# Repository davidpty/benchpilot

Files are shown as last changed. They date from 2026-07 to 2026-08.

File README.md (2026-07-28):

# BenchPilot

**Bench-test your Raymarine autopilot or replace the display on your boat.**

BenchPilot turns an ESP32 touchscreen display (ESP32-2432S028R CYD) into a SeaTalk 1 bus monitor and wireless control head. Connect it to a Raymarine SeaTalk autopilot course computer on the bench or on the water. It generates heading data, decodes autopilot status, and lets you push buttons just like the real ST6002, all through a 320x240 color touchscreen or a WiFi web dashboard on your phone.

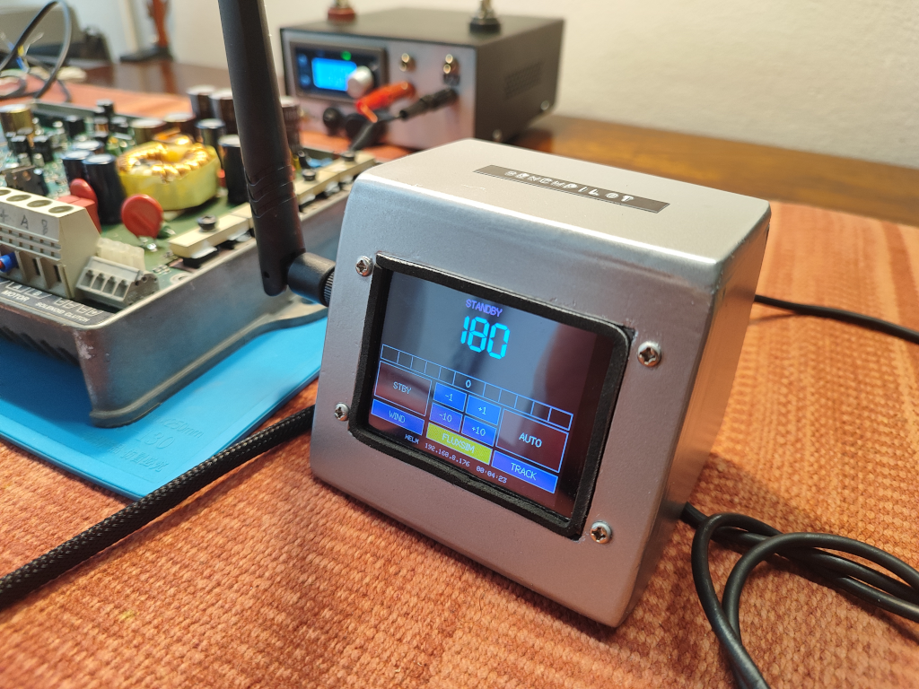
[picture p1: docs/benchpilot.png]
BenchPilot in a PVC foam board housing


## What you can do

- **Replace your display.** Plug it into the existing SeaTalk bus and get heading, rudder, depth, wind, speed, and GPS on the touchscreen with no wiring changes needed.
- **Control from anywhere.** The built-in WiFi web dashboard works on any phone, tablet, or laptop. Adjust course or change modes without reaching for the helm.
- **Monitor.** See all SeaTalk traffic in real time, on-screen or remotely.
- **Simulate.** Built-in heading generator ("FluxSim") sends fake heading datagrams so you can test the autopilot's response on the bench without a compass.
- **Log.** Every bus datagram is saved to the SD card for later analysis.
- **Update.** Flash new firmware over WiFi (OTA) with no cables needed.

You need an ESP32-2432S028R "CYD" display board, a BenchPilot interface
PCB, and a 12V power supply (or the SeaTalk bus itself).

The interface circuit can be built in two ways. The `pcb/` folder contains
a Fritzing file (`BenchPilot_260715.fzz`), schematics, and a DIY etch PDF
(`BenchPilot_260715_diy_etch.pdf`) sized for printing on A4 transfer paper
with a laser printer. Print the PDF, iron the toner onto single-sided
copper clad board, then etch in ferric chloride or ammonium persulfate.
Drill the holes, solder the components, and the board is ready to plug into
the CYD and the SeaTalk bus.

The housing shown in the photo is made from 5mm PVC foam board (Foamex /
Sintra). A craft knife works well for the foam board, it cuts cleanly and
sands smooth. The pieces are glued together with regular PVC glue.

## Getting started

1. Build the interface circuit using the DIY etch PDF or the Fritzing files
2. Copy `src/wifi_config.example.h` to `src/wifi_config.h`, add your WiFi
3. Build and upload with PlatformIO:
   ```
   pio run -t upload
   ```
4. Connect to the BenchPilot WiFi access point or join your network
5. Open http://benchpilot.local in your browser

## License

GNU General Public License v3.0

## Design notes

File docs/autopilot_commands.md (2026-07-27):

# Autopilot Control Reference

## System Architecture

```
ESP32 + BenchPilot Level Shifter (BC557/BC547)
        |
        |  SeaTalk 1 bus (4800 baud, 9-bit, 12V open-collector)
        |
Raymarine ST6002 Display (control head)
        |
Raymarine SmartPilot S3 Course Computer
        |
        |  Motor drive unit
        |
Rudder
```

The ST6002 is the display/control head on the bus. The SmartPilot S3 is the course computer that drives the rudder. The ESP32 (via the discrete transistor level shifter) appears as another device on the bus and can both send commands to and receive status from the autopilot.

## Key Messages for Autopilot

### Transmitted by ESP32 (to control autopilot)

| Message | Command | Function |
|---|---|---|
| 0x86 | Autopilot keystroke | Mode changes, heading changes |
| 0x92 | Set parameter | Response, wind trim, rudder gain |
| 0x87 | Set response level | Deadband control |

### Received by ESP32 (from autopilot)

| Message | Command | Function |
|---|---|---|
| 0x84 | Autopilot status | Heading, mode, rudder, alarms |
| 0x89 | Compass course | Heading from steering compass |
| 0x9C | Heading + rudder | Combined heading and rudder |
| 0x88 | Parameter value | Current parameter settings |
| 0x91 | Rudder gain | Current gain setting |

## Autopilot Commands (0x86)

### Remote Type Encoding

The high nibble of byte 1 encodes the remote type:
- `0x1` = Z101 remote (only sends course changes in Auto mode)
- `0x2` = ST600R remote (full key set — preferred for ESP32)

The AK-Homberger code hard-codes `x = 2` (ST600R remote).

### Command Formats

| Function | Byte 0 | Byte 1 | Byte 2 | Byte 3 | Hex |
|---|---|---|---|---|-----|
| Auto | 0x86 | 0x21 | 0x01 | 0xFE | `86 21 01 FE` |
| Standby | 0x86 | 0x21 | 0x02 | 0xFD | `86 21 02 FD` |
| Track | 0x86 | 0x21 | 0x03 | 0xFC | `86 21 03 FC` |
| Cycle Display | 0x86 | 0x21 | 0x04 | 0xFB | `86 21 04 FB` |
| -1 degree | 0x86 | 0x21 | 0x05 | 0xFA | `86 21 05 FA` |
| -10 degrees | 0x86 | 0x21 | 0x06 | 0xF9 | `86 21 06 F9` |
| +1 degree | 0x86 | 0x21 | 0x07 | 0xF8 | `86 21 07 F8` |
| +10 degrees | 0x86 | 0x21 | 0x08 | 0xF7 | `86 21 08 F7` |
| Decrease Gain | 0x86 | 0x21 | 0x09 | 0xF6 | `86 21 09 F6` |
| Increase Gain | 0x86 | 0x21 | 0x0A | 0xF5 | `86 21 0A F5` |
| Wind/Vane mode | 0x86 | 0x21 | 0x23 | 0xDC | `86 21 23 DC` |
| Return to course | 0x86 | 0x21 | 0x41 | 0xBE | `86 21 41 BE` |

### Extended Commands (Long Press / Hold)

When a key is held for >1 second, the command byte has 0x40 OR'd in:

| Function | Command | Notes |
|---|---|---|
| -1 held | 0x45 | Repeated while held |
| -10 held | 0x46 | Repeated while held |
| +1 held | 0x47 | Repeated while held |
| +10 held | 0x48 | Repeated while held |
| Track held | 0x43 | Long press |
| Disp held | 0x44 | Long press |
| Auto held | 0x41 | Also = Return to course |

When a key is held in the "repeat" pattern (0x80-0x83):
| Function | Command | Notes |
|---|---|---|
| Hold -1 | 0x80 | Repeated every second |
| Hold -10 | 0x81 | Repeated every second |
| Hold +1 | 0x82 | Repeated every second |
| Hold +10 | 0x83 | Repeated every second |
| Release held key | 0x84 | Sent when held key is released |

## Messages Received from Autopilot

### 0x84 Status — Complete Field Reference

```
84 u6 vw xy 0z 0m rr ss tt
```

#### Heading Decoding

The compass heading is encoded across byte 1 (high nibble `u`) and byte 2 (`vw`):

```
u = first_nibble(datagram[1])    // from high nibble of byte 1
vw = datagram[2]                  // byte 2
xy = datagram[3]                  // byte 3
z = last_nibble(datagram[4])      // byte 4 low nibble
m = last_nibble(datagram[5])      // byte 5 low nibble
rr = datagram[6]                  // byte 6 (signed)
ss = datagram[7]                  // byte 7
tt = datagram[8]                  // byte 8
```

**Compass heading:**
```c
heading = ((u & 0x03) * 90) + ((vw & 0x3f) * 2) + offset
where offset = 0 if (u & 0x0c) == 0
               1 if (u & 0x0c) == 0x04
               1 if (u & 0x0c) == 0x08
               2 if (u & 0x0c) == 0x0c
// Simplified: offset = (u >> 3)  // bit 3 is 1 = +1°, bits 2-3 both 1 = +2°
```

**Target heading:**
```c
target = (((vw & 0xc0) >> 6) * 90) + (xy / 2)
```

#### Example: 84 26 A2 88 40 00 FE 02 06

| Byte | Value | Meaning |
|---|---|---|
| 0 | 0x84 | Autopilot status |
| 1 | 0x26 | u = 2, length = 6 (9 bytes total) |
| 2 | 0xA2 | vw = 162 |
| 3 | 0x88 | xy = 136 |
| 4 | 0x40 | z = 0 (Standby) |
| 5 | 0x00 | m = 0 (no alarms) |
| 6 | 0xFE | rr = -2° (rudder 2° left) |
| 7 | 0x02 | ss = 0x02 (display on, 400G) |
| 8 | 0x06 | tt = 0x06 (computer type) |

**Decoded:**
- Heading: `((2 & 3) * 90) + ((162 & 0x3f) * 2) + ((2 & 0x0c) ? (((2 & 0x0c) == 0x0c) ? 2 : 1) : 0)`
  = `(2 * 90) + (34 * 2) + (0)` = 180 + 68 = **248°**
- Target: `(((162 & 0xc0) >> 6) * 90) + (136 / 2)` = `(2 * 90) + 68` = **248°**
- Mode: Standby
- Rudder: -2° (FE = -2 in two's complement)

#### Mode State Table

| z value | AUTOPILOT_MODE | Description |
|---|---|---|
| 0x00 | STANDBY | Autopilot disengaged; manual steering |
| 0x02 | AUTO | Autopilot engaged, holding heading |
| 0x04 | VANE (WIND) | Autopilot tracking wind angle |
| 0x08 | TRACK | Autopilot navigating to waypoint |

#### Alarm / Sub-mode

| m bit | Alarm | Description |
|---|---|---|
| 0x04 | Off Course | Boat deviated from target heading |
| 0x08 | Wind Shift | Wind angle changed significantly in Vane mode |

#### Display Flags

| ss bit | Meaning |
|---|---|
| 0x01 | Turn off heading display |
| 0x02 | Always on |
| 0x08 | "No data" |
| 0x10 | "Large XTE" (large cross-track error) |
| 0x80 | "Auto rel" (auto release) |

## Parameter Commands

### 0x92 — Set Parameter (5 bytes)

**Format**: `92 02 <param> <value> 00`

| Parameter ID | Name | Range | Description |
|---|---|---|---|
| 0x01 | Rudder Gain | 1-9 | Controls how aggressively the pilot responds to heading error |
| 0x11 | Wind Trim | 1-9 | Wind angle adjustment in Vane mode |
| 0x12 | Response Level | 1-9 | Overall autopilot response/aggressiveness |

### Reading Parameter Values

To trigger the autopilot to broadcast its current parameter settings, send the 0x92 command followed by a 0x86 display command. The autopilot responds with 0x88 or 0x91 on the bus.

From `raymarine_autopilot_pi`:
```
Get Response Level:  $STALK,92,02,12,0X,00
                     $STALK,86,21,2E,D1      (toggle response display)
Get Rudder Gain:     $STALK,92,02,01,0X,00
                     $STALK,86,21,6E,91      (enter rudder gain display)
Get Wind Trim:       $STALK,92,02,11,0X,00
```

Where `0X` is the desired value. The 0x86 display command causes the autopilot to echo the current parameter.

### 0x88 — Autopilot Parameter Broadcast (6 bytes) — Receive

**Format**: `88 03 ww xx yy zz`

| Byte | Field |
|---|---|
| 2 | `ww` = parameter number |
| 3 | `xx` = current value |
| 4 | `yy` = minimum value |
| 5 | `zz` = maximum value |

### 0x91 — Set Rudder Gain / Response (3 bytes) — Both

**Format**: `91 00 0x`

When sent: set the rudder gain (1-9). When received: current rudder gain setting.

## Parameter 0x92 — Response Level (from raymarine_autopilot_pi plugin)

```
$STALK,92,02,12,<value>,00
```

Used to change the autopilot's response level (1-9, where 1 is least responsive, 9 is most responsive). The parameter is stored in the course computer EEPROM.

## Commands for ST6002 / SmartPilot S3

### Mode Transitions

```
                    ┌─────────┐
         ┌─────────→│ STANDBY │←──────────┐
         │          └─────────┘           │
         │  0x86/01    │                  │  0x86/02
         │             ▼                  │
         │          ┌──────┐              │
         ├─────────→│ AUTO │──────────────┤
         │          └──────┘              │
         │  0x86/23   │                   │
         │            ▼                   │
         │          ┌──────┐              │
         └─────────→│ WIND │──────────────┘
                     └──────┘
         ┌─────────→│ TRACK│──────────────┘
                     0x86/03
```

### Course Changes (in Auto or Wind mode)

When in AUTO or WIND mode, the +1/-1 and +10/-10 commands adjust the target heading:

```
+1 (0x07): Target heading += 1°
-1 (0x05): Target heading -= 1°
+10 (0x08): Target heading += 10°
-10 (0x06): Target heading -= 10°
```

The heading wraps around at 0/360.

### Implementation Guidance

**Timing:**
- Inter-command delay: at least 300 ms (AK-Homberger uses `KEY_DELAY=300` for debounce)
- Inter-byte delay: 3 ms between bytes in a single message
- Max retries: 5 attempts with random 2-50 ms backoff

**Keepalive:**
- NMEA Bridge ID (0x90): every 10 seconds (for SeaTalk-NG converter compatibility)
- Wind data refresh: monitor bus for 0x11 messages

**Safety:**
- Beep safety timeout: send beep-off after 3 seconds to prevent stuck alarm
- Data timeout: status values older than 5 seconds are considered stale
- Command timeout: 3 seconds max wait for command acknowledgement

### State Machine for ESP32

```
IDLE → waiting for commands (serial, RF, or network)
    ↓
COMMAND_RECEIVED → validate command
    ↓
CSMA_CD → listen for bus silence
    ↓
TRANSMIT → send datagram byte-by-byte with collision check
    ↓
ACK_WAIT → verify no collision
    ↓
IDLE → return to idle
```

On collision: random backoff (2-50ms), retry up to 5 times.
On persistent failure: report error, return to IDLE.

## NMEA0183 Wrapping (for reference via SeaTalk Link converters)

When the SeaTalk bus is accessed through an NMEA0183-to-SeaTalk converter (Raymarine SeaTalk Link or similar), messages are wrapped:

**Status received** (0x84 from autopilot):
```
$STALK,84,26,A2,88,40,00,FE,02,06*15
```

**Command sent** (0x86 to autopilot):
```
$STALK,86,21,01,FE*4E
$STALK,86,21,07,F8*4B
```

**Parameter request**:
```
$STALK,92,02,12,05,00*47
```

The NMEA XOR checksum is computed over all bytes between `$` (exclusive) and `*` (exclusive).

## Limitations and Safety Considerations

1. **Single master**: The SeaTalk bus is peer-to-peer; any device can transmit. But only one message at a time. Always use CSMA/CD.

2. **No guaranteed delivery**: There is no ACK/NAK protocol at the transport layer. Collision detection only verifies the bus state, not that the intended receiver processed the message.

3. **Mode-dependent commands**: Course change commands (+1/-1/+10/-10) are only valid when the autopilot is in AUTO, WIND, or TRACK mode. In STANDBY, they have no effect.

4. **Heading wrap**: 0-359 degrees. The autopilot handles shortest-path heading changes internally.

5. **Power cycling**: When the ST6002 or SmartPilot S3 is first powered, it broadcasts 0x83 (clear failure) and 0x89 (heading). Wait for a 0x84 status message before sending commands.

6. **Response level caution**: Setting response level too high (8-9) can cause unstable steering in rough seas. Start with level 3-5.

7. **Tacking**: The tack commands (0x21, 0x22) require the autopilot to be in WIND mode. They tack through the wind by ~90° (port or starboard).

8. **Held keys**: Holding a course change key (0x80-0x83) causes the heading to change continuously. Must send 0x84 to stop. Not recommended for ESP32 use unless specifically needed.

9. **Bus loading**: Keep message rate reasonable. The AK-Homberger project sends bridge ID every 10 seconds. Avoid flooding the bus.

10. **Data freshness**: Implement timeouts. If no 0x84 message received for 12 seconds (James Roscoe plugin watchdog), consider the autopilot offline.

## Relevant Source Files

| File | Repository | Content |
|---|---|---|
| `seatalk_datagram.c:1030-1097` | James Roscoe (refs/seatalk) | Build/parse 0x84 status |
| `seatalk_datagram.c:1177-1211` | James Roscoe (refs/seatalk) | Build/parse 0x86 commands |
| `seatalk_datagram.h:13-45` | James Roscoe (refs/seatalk) | Command enum definitions |
| `seatalk_command.c:78-84` | James Roscoe (refs/seatalk) | Command send function |
| `seatalk_protocol.c:358-375` | James Roscoe (refs/seatalk) | 0x84 status update handler |
| `ArduinoPilotMicro433WindNG.ino` | AK-Homberger | Complete working implementation |
| `autopilot_pi.cpp` | raymarine_autopilot_pi | NMEA0183 SeaTalk wrapping |

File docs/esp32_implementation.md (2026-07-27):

# ESP32 Implementation

## 1. Overview

This document describes the BenchPilot implementation of SeaTalk 1 communication on an ESP32 using a discrete transistor level shifter (BC557/BC547) circuit. The ESP32 (ESP32-2432S028 CYD) replaces the Arduino Pro Micro used in reference projects.

## 2. Hardware Interface

### BenchPilot Circuit Board

The BenchPilot level shifter uses two discrete transistors (no 74LS07):

| Component | Function |
|---|---|
| Q1 (BC557 PNP) | Inverting level translator: 12V SeaTalk → 3.3V ESP32 RX |
| Q2 (BC547 NPN) | Inverting level translator: 3.3V ESP32 TX → 12V SeaTalk |
| R1 (10K), R2 (2.2K) | Base bias for Q1 |
| R3 (10K), R4 (3.9K) | Base pulldown + current limit for Q2 |
| R5 (6.8K), R6 (27K) | Voltage divider on Q1 output for ESP32 safe level (~2.5V) |
| U1 (DC-DC) | 12V → 3.3V step-down for ESP32 power |

### Circuit Behavior

| Path | ESP32 Pin | Transistor | SeaTalk Bus |
|---|---|---|---|
| TX idle | GPIO 22 = 0V (LOW) | Q2 OFF | 12V (idle, correct) |
| TX active | GPIO 22 = 3.3V (HIGH) | Q2 ON | 0V (active, correct) |
| RX idle | GPIO 35 = 0V (LOW) | Q1 OFF | 12V (idle, correct) |
| RX active | GPIO 35 = ~2.5V (HIGH) | Q1 ON | 0V (active, correct) |

Both paths are **inverting**. The firmware compensates via `uart_set_line_inverse()`.

### GPIO Pin Mapping (Actual)

| Signal | ESP32 Pin | Notes |
|---|---|---|
| SeaTalk RX | GPIO 35 | UART2 RX, inverted via Q1 |
| SeaTalk TX | GPIO 22 | UART2 TX, inverted via Q2 |
| TFT DC | GPIO 2 | CYD display — do not use for other purposes |
| TFT Backlight | GPIO 21 | Controlled via TFT_BL_PIN |
| Display | ILI9341 | SPI, 40 MHz, rotation 1 (landscape) |

### Power

- ESP32 powered via on-board DC-DC step-down from 12V SeaTalk bus
- The CYD board has its own 3.3V regulator — no LM7805 needed
- Current budget: ESP32 ~80mA, display backlight ~40mA, interface ~5mA, total <150mA

## 3. UART Configuration

### Current Approach (8N1 with err_wr_mask = 0)

The firmware uses UART2 in standard 8N1 mode at 4800 baud. SeaTalk requires 9-bit (8 data + 1 command bit), but the 9th bit (command marker) is **not distinguished** in the current receive-only implementation — all bytes are treated as data. This works because:

1. SeaTalk command bytes always have the correct framing from the bus
2. The UART will frame-sync on the stop bit of each byte
3. Datagram boundaries are determined by the message length field (byte 1 low nibble), not the 9th bit

### Register Setup

```cpp
Seatalk.begin(4800, SERIAL_8N1, SEATALK_RX_PIN, SEATALK_TX_PIN);

// Both RX and TX are inverted by the transistor circuit
uart_set_line_inverse(UART_NUM_2,
    (SEATALK_RX_INVERT ? UART_SIGNAL_RXD_INV : 0) |
    (SEATALK_TX_INVERT ? UART_SIGNAL_TXD_INV : 0));

// Clear UART error-write-mask to avoid dropped bytes on framing errors
REG_CLR_BIT(UART_CONF0_REG(UART_NUM_2), UART_ERR_WR_MASK);
```

The `REG_CLR_BIT` macro (from `soc/uart_reg.h`) is used instead of struct-based register writes to avoid racing with the UART ISR (which caused boot loops).

### Future: 9-Bit Mode

For full 9-bit support (needed for transmit with command-bit awareness), options include:

1. **UART RS485 mode** with 9-bit addressing — use `UART_RS485_CONF_REG`
2. **RMT peripheral** — bit-bang with precise hardware timing
3. **9-bit register hack** — `WRITE_PERI_REG(UART_CONF0_REG(2), ...)` to set `UART_BIT_NUM = 3`

The current implementation does not require 9-bit mode for receive.

## 4. Receive Strategy

### UART Polling in loop()

```cpp
while (Seatalk.available() > 0) {
    uint8_t b = Seatalk.read();
    totalBytes++;
    lastPacketTime = millis();
    processByte(b);
}
```

No interrupts. The main loop polls UART2 at every iteration. At 4800 baud (~2ms per byte), this is well within the ESP32's capacity.

### Datagram Framing (processByte)

The `processByte()` function implements a simple byte-oriented state machine:

1. Buffer resets after a 50ms inter-message timeout (gap between SeaTalk datagrams)
2. On receiving ≥3 bytes, reads the length from byte 1's low nibble: `len = 3 + (attr & 0x0F)`
3. When the full datagram is assembled, parses known message types (0x84, 0x9C, 0x89, 0x10)
4. Message text is logged to a circular buffer for TFT display and web UI

### SeaTalk Message Decoding

| Command | Description | Fields Extracted |
|---|---|---|
| 0x84 (9 bytes) | Autopilot status | Heading, rudder position |
| 0x9C (4 bytes) | Compass heading + rudder | Heading, rudder |
| 0x89 (5 bytes) | Steering compass course | Heading |
| 0x10 (4 bytes) | Apparent wind angle | Heading (from wind instrument) |
| 0x90 (5 bytes) | Device identification | System type |

Heading decode formula (used for 0x84, 0x9C, 0x89, 0x10):

```cpp
uint8_t u = (byte1 >> 4) & 0x0F;
int deg = ((u & 3) * 90) + ((byte2 & 0x3F) * 2)
        + ((u & 0x0C) ? (((u & 0x0C) == 0x0C) ? 2 : 1) : 0);
if (deg > 360) deg -= 360;
```

### Logging

- Ring buffer: 30 entries, 19 shown on TFT, 20 shown on web UI
- Each entry: hex dump of the datagram bytes + decoded heading/rudder if applicable

## 5. Transmit Strategy (Planned)

### TX Pin Configuration

TX is configured on GPIO 22 with **inversion enabled** (`UART_SIGNAL_TXD_INV`). The UART idle state (logic 1) becomes 0V on the pin, keeping Q2 OFF and the bus at 12V. When a byte is transmitted:

1. Start bit (logic 0) → inverted to 3.3V → Q2 ON → bus pulled to 0V
2. Data bits are transmitted LSB-first, each inverted by the UART
3. Stop bit (logic 1) → inverted to 0V → Q2 OFF → bus returns to 12V

### CSMA/CD Implementation (from AK-Homberger pattern)

When transmit is implemented, the algorithm will be:

```cpp
bool sendDatagram(uint8_t *data, int len) {
    for (int retry = 0; retry < 5; retry++) {
        // 1. Listen — drain any pending RX bytes
        while (Seatalk.available()) {
            Seatalk.read();
            delay(3);
        }
        // 2. Transmit byte-by-byte with collision check
        bool ok = true;
        for (int i = 0; i < len; i++) {
            Seatalk.write(data[i]);
            delay(3);
            if (Seatalk.available()) {
                uint8_t inbyte = Seatalk.read();
                if (inbyte != data[i]) { ok = false; break; }
            } else { ok = false; break; }
        }
        if (ok) return true;
        delay(random(2, 50));  // random backoff
    }
    return false;
}
```

### Command Queue

- Single command buffer (no queue depth needed for user-initiated commands)
- 300ms debounce between commands (ST6002 limit)
- Commands: 0x86 autopilot keystrokes (Auto, Standby, +1°, -1°, +10°, -10°)

## 6. Software Architecture

### Module Layout (Actual)

```
src/
├── main.cpp                 # Main firmware: WiFi, OTA, WebServer, SeaTalk RX
├── wifi_config.h            # WiFi credentials (gitignored)
lib/cyd_config/
├── User_Setup.h             # TFT_eSPI configuration for CYD
docs/
├── seatalk_protocol.md      # SeaTalk protocol reference
├── seatalk_messages.md       # Message dictionary
├── autopilot_commands.md     # Autopilot control reference
├── esp32_implementation.md   # This document
├── SeaTalkToESP32-Circuit.txt # Circuit schematic description
├── SeaTalkToESP32-Circuit.png # Circuit schematic image
```

### Firmware Architecture (main.cpp)

```
setup()
├── Backlight on (GPIO 21)
├── TFT init (ILI9341, rotation 1)
├── drawStatusBar()
├── WiFi begin (STA mode)
├── ArduinoOTA begin
├── UART2 begin (4800 8N1, RX=35, TX=22)
│   ├── uart_set_line_inverse (RX + TX)
│   └── REG_CLR_BIT (err_wr_mask)
└── WebServer begin

loop()
├── ArduinoOTA.handle()
├── server.handleClient()
├── WiFi status check
├── while Seatalk.available():
│   ├── read byte
│   ├── totalBytes++
│   └── processByte()
└── updateDisplay() (every 500ms)
```

### Configurable Parameters

| Parameter | Value | Defined In |
|---|---|---|
| Baud rate | 4800 | `SEATALK_BAUD` |
| RX pin | GPIO 35 | `SEATALK_RX_PIN` |
| TX pin | GPIO 22 | `SEATALK_TX_PIN` |
| RX invert | ON | `SEATALK_RX_INVERT` |
| TX invert | ON | `SEATALK_TX_INVERT` |
| Blue LED pin | GPIO 27 | `TFT_BL_PIN` |
| Message log size | 30 entries | `MSG_LOG_SIZE` |
| Display refresh | 500ms | Hard-coded in `updateDisplay()` |
| Bus idle timeout | 50ms | Hard-coded in `processByte()` |

## 7. Differences from Reference Implementations

| Aspect | AK-Homberger (Arduino) | James Roscoe (Linux) | BenchPilot (ESP32) |
|---|---|---|---|
| MCU | ATmega32U4 @ 16 MHz | Linux (RPi GPIO) | ESP32 @ 240 MHz |
| Level shifter | 74LS07 (non-inverting) | None (3.3V GPIO direct) | BC557/BC547 (inverting ×2) |
| TX compensation | None needed | None (bit-bang) | `UART_SIGNAL_TXD_INV` |
| RX compensation | None needed | Inverted GPIO reads | `UART_SIGNAL_RXD_INV` |
| 9-bit mode | Patched HardwareSerial | Bit-bang with hrtimer | err_wr_mask = 0 (8N1) |
| Display | OLED SSD1306 (I2C) | None | TFT ILI9341 (SPI) |
| Communication | 433 MHz RF + serial | OpenCPN plugin | WiFi + HTTP API |
| Bus arbitration | CSMA/CD with UART | CSMA/CD with bit-bang | Not yet implemented |

## 8. Key Source Files Reference

| File | Location | What to Steal |
|---|---|---|
| `ArduinoPilotMicro433WindNG.ino` | `refs/Seatalk-Autopilot-Remote-Control/` | CSMA/CD sendDatagram(), message constants |
| `seatalk_datagram.c` | `refs/seatalk/` | All build/parse functions, compass encoding |
| `seatalk_datagram.h` | `refs/seatalk/` | All message constants, command enums |
| `seatalk_transport_layer.c` | `refs/seatalk/` | State machine, byte Tx/Rx logic |
| `autopilot_pi.cpp` | `refs/raymarine_autopilot_pi/` | 0x84/0x86/0x92 complete reference |
| `HardwareSerial9bit/` | `refs/Seatalk-Autopilot-Remote-Control/` | 9-bit serial pattern for reference |

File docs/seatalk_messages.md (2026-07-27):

# SeaTalk 1 Message Dictionary

## Message Format Summary

All SeaTalk datagrams follow this structure:

```
Byte 0: Command byte (9th bit = 1)
Byte 1: [High nibble: flags] [Low nibble: payload_length = total_bytes - 3]
Byte 2..N-1: Payload (N = low_nibble + 3)
Byte N: Optional checksum (message-dependent)
```

## Complete Message Table

| Cmd | Len | Name | Direction | Source |
|-----|-----|---|---|---|
| 0x00 | 5 | Depth Below Transducer | Receive | Knauf/Roscoe |
| 0x01 | — | Equipment ID | Receive | Knauf |
| 0x05 | 6 | Engine RPM and Blade Pitch | Receive | Knauf/Roscoe |
| 0x10 | 4 | Apparent Wind Angle | Both | Knauf/Roscoe |
| 0x11 | 4 | Apparent Wind Speed | Both | Knauf/Roscoe |
| 0x20 | 4 | Water Speed | Both | Knauf/Roscoe |
| 0x21 | 5 | Trip Mileage | Receive | Knauf/Roscoe |
| 0x22 | 5 | Total Mileage | Receive | Knauf/Roscoe |
| 0x23 | 4 | Water Temperature (basic) | Receive | Knauf/Roscoe |
| 0x24 | 5 | Display Units | Receive | Knauf/Roscoe |
| 0x25 | 7 | Total & Trip Log | Receive | Knauf/Roscoe |
| 0x26 | 7 | Water Speed with Average | Receive | Knauf/Roscoe |
| 0x27 | 4 | Precise Water Temperature | Receive | Knauf/Roscoe |
| 0x30 | 3 | Set Lamp Intensity | Transmit | Knauf/Roscoe |
| 0x36 | 3 | Cancel MOB | Transmit | Knauf/Roscoe |
| 0x38 | 4 | Codelock Data | Receive | Knauf |
| 0x50 | 5 | Latitude Position | Receive | Knauf/Roscoe |
| 0x51 | 5 | Longitude Position | Receive | Knauf/Roscoe |
| 0x52 | 4 | Speed Over Ground | Both | Knauf/Roscoe |
| 0x53 | 3 | Course Over Ground | Both | Knauf/Roscoe |
| 0x54 | 4 | GMT Time | Receive | Knauf/Roscoe |
| 0x56 | 4 | Date | Receive | Knauf/Roscoe |
| 0x57 | 3 | Satellite Info | Receive | Knauf/Roscoe |
| 0x58 | 8 | Lat/Lon Combined Position | Receive | Knauf/Roscoe |
| 0x59 | 5 | Set Countdown Timer | Transmit | Knauf/Roscoe |
| 0x66 | 3 | Wind Alarm | Both | Knauf/Roscoe |
| 0x68 | 4 | Alarm Acknowledgement | Both | Knauf/Roscoe |
| 0x6E | 10 | MOB Keystroke | Receive | Knauf |
| 0x70 | 3 | ST60 Remote Keystroke | Receive | Knauf |
| 0x80 | 3 | Set Lamp Intensity (alt) | Transmit | Knauf |
| 0x81 | 3/4 | Course Computer Setup | Receive | Knauf |
| 0x82 | 8 | Target Waypoint Name | Both | Knauf/Roscoe |
| 0x83 | 10 | Course Computer Failure | Receive | Knauf/Roscoe |
| **0x84** | **9** | **Autopilot Status** | **Receive** | **All** |
| 0x85 | 9 | Navigation to Waypoint | Receive | Knauf/Roscoe |
| **0x86** | **4** | **Autopilot Command** | **Transmit** | **All** |
| 0x87 | 3 | Set Autopilot Response Level | Both | Knauf/Roscoe |
| 0x88 | 6 | Autopilot Parameter | Receive | Knauf/Roscoe |
| 0x89 | 5 | Steering Compass Course | Both | Knauf/Roscoe |
| 0x90 | 5 | Device Identification | Both | Knauf |
| 0x91 | 3 | Set Rudder Gain / Response | Both | Knauf/Roscoe |
| 0x92 | 5 | Set Autopilot Parameter | Transmit | Knauf/Roscoe |
| 0x93 | 3 | Enter Autopilot Setup | Transmit | Knauf |
| 0x95 | 9 | Autopilot Status (setting mode) | Receive | Knauf |
| 0x99 | 3 | Compass Variation | Receive | Knauf/Roscoe |
| 0x9A | 12 | Version String | Receive | Knauf |
| **0x9C** | **4** | **Compass Heading & Rudder Position** | **Both** | **Knauf/Roscoe** |
| 0x9E | 15 | Waypoint Definition | Both | Knauf |
| 0xA1 | 16 | Destination Waypoint Info | Receive | Knauf |
| 0xA2 | 7 | Waypoint Arrival Notice | Receive | Knauf |
| 0xA4 | 5/9 | Broadcast Query / Identity | Both | Knauf |
| 0xA5 | 4/7/10/16 | GPS/DGPS Fix Info | Receive | Knauf/Roscoe |
| 0xA8 | 6 | Alarm Notice | Receive | Knauf |
| 0xAB | 6 | Alarm Notice | Receive | Knauf |

## Critical Messages for Autopilot

### 0x84 — Autopilot Status (9 bytes) — Receive Only

Broadcast periodically by the autopilot course computer (SmartPilot S3). Contains heading, target course, mode, rudder position, and alarms.

**Format**: `84 u6 vw xy 0z 0m rr ss tt`

| Byte | Variable | Description |
|---|---|---|
| 0 | 0x84 | Command byte |
| 1 | `u` | High nibble: heading encoding + turn direction |
| 2 | `vw` | Low 6 bits: compass heading continuation. High 2 bits: target heading high bits |
| 3 | `xy` | Target heading low byte: `(target % 90) * 2` |
| 4 | `z` | Mode (low nibble only): 0=Standby, 2=Auto, 4=Wind/Vane, 8=Track |
| 5 | `m` | Alarms: bit 2=Off Course, bit 3=Wind Shift |
| 6 | `rr` | Rudder position in degrees (signed, positive = right) |
| 7 | `ss` | Display flags |
| 8 | `tt` | Computer type: 0x08=400G, 0x05=150(G) |

**Heading decoding** (`parse_autopilot_status` in `seatalk_datagram.c:1070`):
```c
compass_heading = ((u & 0x03) * 90) + ((vw & 0x3f) * 2) +
                  ((u & 0x0c) ? (((u & 0x0c) == 0x0c) ? 2 : 1) : 0);
turning_direction = (u & 0x08) ? RIGHT : LEFT;
target_heading = (((vw & 0xc0) >> 6) * 90) + (xy / 2);
rudder_position = fix_twos_complement(rr);
```

**Mode decoding**:
| z value | Mode |
|---|---|
| 0x0 | Standby |
| 0x2 | Auto |
| 0x4 | Wind/Vane |
| 0x8 | Track |

**Alarm bits** (byte 5, low nibble `m`):
| Bit | Alarm |
|-----|---|
| 0x04 | Off Course |
| 0x08 | Wind Shift |

**Example hex packet**: `84 26 A2 88 40 00 FE 02 06`
- compass heading: `u=2, vw=0xA2(162)` → `(2&3)*90 + (162&0x3f)*2 + ...` → heading ~180°
- target heading: `((162&0xc0)>>6)*90 + (0x88/2)` → heading ~180°
- mode = 0 (Standby)
- rudder = -2° (0xFE is -2 in two's complement)

### 0x86 — Autopilot Command (4 bytes) — Transmit

**Format**: `86 x1 yy !yy`

| Byte | Variable | Description |
|---|---|---|
| 0 | 0x86 | Command byte |
| 1 | `x` | High nibble: remote type (1=Z101, 2=ST600R). Low nibble: always 1 (4-byte message) |
| 2 | `yy` | Sub-command (see table below) |
| 3 | `!yy` | Checksum = `yy ^ 0xFF` (bitwise complement) |

**Validation** (`parse_autopilot_command`):
```c
if ((yy | yy_comp) != 0xff) → checksum error
```

### 0x86 Sub-Command Table

| Hex | Constant | Function |
|-----|---|---|
| 0x01 | `ST_AUTOPILOT_COMMAND_AUTO` | Engage Auto mode |
| 0x02 | `ST_AUTOPILOT_COMMAND_STANDBY` | Disengage to Standby |
| 0x03 | `ST_AUTOPILOT_COMMAND_TRACK` | Engage Track mode |
| 0x04 | `ST_AUTOPILOT_COMMAND_DISP` | Cycle display |
| 0x05 | `ST_AUTOPILOT_COMMAND_TURN_LEFT_1` | -1 degree course change |
| 0x06 | `ST_AUTOPILOT_COMMAND_TURN_LEFT_10` | -10 degrees course change |
| 0x07 | `ST_AUTOPILOT_COMMAND_TURN_RIGHT_1` | +1 degree course change |
| 0x08 | `ST_AUTOPILOT_COMMAND_TURN_RIGHT_10` | +10 degrees course change |
| 0x09 | `ST_AUTOPILOT_COMMAND_DECREASE_GAIN` | Decrease rudder gain |
| 0x0A | `ST_AUTOPILOT_COMMAND_INCREASE_GAIN` | Increase rudder gain |
| 0x21 | `ST_AUTOPILOT_COMMAND_TACK_LEFT` | Tack port |
| 0x22 | `ST_AUTOPILOT_COMMAND_TACK_RIGHT` | Tack starboard |
| 0x23 | `ST_AUTOPILOT_COMMAND_WIND_MODE` | Engage Wind/Vane mode |
| 0x28 | `ST_AUTOPILOT_COMMAND_TRACK_MODE` | Engage Track mode (alt) |
| 0x2E | `ST_AUTOPILOT_COMMAND_TOGGLE_RESPONSE_LEVEL` | Toggle response display |
| 0x41 | `ST_AUTOPILOT_COMMAND_RETURN_TO_COURSE` | Resume previous course |
| 0x63 | `ST_AUTOPILOT_COMMAND_RETURN_TO_WIND_ANGLE` | Resume previous wind angle |
| 0x6E | `ST_AUTOPILOT_COMMAND_ENTER_RUDDER_GAIN_MODE` | Enter rudder gain display |
| 0x80–0x83 | `HOLD_*` | Held key (repeated every second) |
| 0x84 | `ST_AUTOPILOT_COMMAND_RELEASE_HELD_KEY` | Release held key |

**Complete command packets** (from AK-Homberger):

| Command | Byte 0 | Byte 1 | Byte 2 | Byte 3 |
|---|---|---|---|---|
| Auto | 0x86 | 0x21 | 0x01 | 0xFE |
| Standby | 0x86 | 0x21 | 0x02 | 0xFD |
| +1° | 0x86 | 0x21 | 0x07 | 0xF8 |
| -1° | 0x86 | 0x21 | 0x05 | 0xFA |
| +10° | 0x86 | 0x21 | 0x08 | 0xF7 |
| -10° | 0x86 | 0x21 | 0x06 | 0xF9 |
| Track | 0x86 | 0x21 | 0x03 | 0xFC |
| Wind | 0x86 | 0x21 | 0x23 | 0xDC |

### 0x9C — Compass Heading & Rudder Position (4 bytes) — Transmit

**Format**: `9C u1 vw rr`

Used to transmit heading and rudder data to the bus (e.g., from a fluxgate compass or rudder sensor).

| Byte | Content |
|---|---|
| 0 | 0x9C |
| 1 | High nibble: heading encoding (`u`). Low nibble: always 1 (4-byte msg) |
| 2 | `vw`: Low 6 bits = heading continuation. High 2 bits reserved |
| 3 | `rr`: Rudder position (signed), degrees right positive |

Heading decoding (same algorithm as 0x84):
```c
heading = (((u & 0x3) * 90) + ((vw & 0x3f) * 2) +
           (u & 0xc ? ((u & 0xc) == 0xc ? 2 : 1) : 0)) % 360;
```

### 0x89 — Steering Compass Course (5 bytes) — Transmit

**Format**: `89 u2 VW XY 2Z`

| Byte | Content |
|---|---|
| 0 | 0x89 |
| 1 | High nibble: heading bits |
| 2 | `VW`: Low 6 bits = heading. High 2 bits = locked heading high bits |
| 3 | `XY`: Locked heading × 2 |
| 4 | Low nibble: bit 1 = locked steer active, bit 5 always set |

## Sensor Messages

### 0x10 — Apparent Wind Angle (4 bytes)

**Format**: `10 01 xx yy`

Scaling: angle = `(xxyy / 2)` degrees right of bow (signed, 0 = head-to-wind)

### 0x11 — Apparent Wind Speed (4 bytes)

**Format**: `11 01 xx 0y`

Speed: `(xx & 0x7f) * 10 + y` knots (or m/s if `xx & 0x80`)

### 0x20 — Water Speed (4 bytes)

**Format**: `20 01 xx xx`

Scaling: `xxxx / 10` knots

### 0x00 — Depth Below Transducer (5 bytes)

**Format**: `00 02 yz xx xx`

Scaling: `xxxx / 10` feet. `y` bits: anchor alarm, metric. `z` bits: deep/shallow alarm, transducer fault.

### 0x52 — Speed Over Ground (4 bytes)

**Format**: `52 01 xx xx`

Scaling: `xxxx / 10` knots

### 0x53 — Course Over Ground (3 bytes)

**Format**: `53 u0 vw`

Degrees: `(u & 0x3) * 90 + (vw & 0x3f) * 2 + (u >> 3)`

## Parameter Commands

### 0x92 — Set Autopilot Parameter (5 bytes) — Transmit

**Format**: `92 02 <param> <value> 00`

| Parameter | Code | Description |
|---|---|---|
| Response level | 0x12 | Sets autopilot response (1-9) |
| Wind trim | 0x11 | Sets wind trim (1-9) |
| Rudder gain | 0x01 | Sets rudder gain (1-9) |

### 0x87 — Set Autopilot Response Level (3 bytes) — Both

**Format**: `87 00 0x`

`x`: 0 = automatic deadband, 1 = minimum deadband (or 1-9 response level from other sources)

### 0x91 — Set Rudder Gain (3 bytes) — Both

**Format**: `91 00 0x`

`x`: rudder gain value (1-9)

## Alarm Commands

### 0xA8 / 0xAB — Alarm Notice (6 bytes)

**Format**: `A8 03 xx yy zz ww`

Used by Guard #1 / Guard #2 alarm systems. Byte 2 identifies alarm type.

### 0x68 — Alarm Acknowledgement (4 bytes) — Transmit

**Format**: `68 x1 yy 00`

`x` identifies alarm type (1=shallow, 2=deep, 3=anchor, 4-11=wind alarms). `yy` = acknowledging device ID (hardcoded to 0x01).

### 0x66 — Wind Alarm (3 bytes)

**Format**: `66 00 xy`

`x` high nibble: apparent wind alarms. `y` low nibble: true wind alarms. Bits: 8=angle low, 4=angle high, 2=speed low, 1=speed high.

## Navigation Messages

### 0x82 — Target Waypoint Name (8 bytes)

**Format**: `82 05 xx !xx yy !yy zz !zz`

Four 6-bit ASCII characters encoded across 6 bytes with complement checksums. Characters must be uppercase, subtract 0x30 before encoding.

### 0x85 — Waypoint Navigation Status (9 bytes)

**Format**: `85 x6 xx vu zw zz yf 00 !yf`

Contains cross-track error, bearing to waypoint, distance, and direction to steer. Byte 8 is complement checksum of byte 6.

### 0x58 — Lat/Lon Position (8 bytes)

**Format**: `58 z5 la xx yy lo qq rr`

Latitude: `la` degrees, `xxyy / 1000` minutes. Longitude: `lo` degrees, `qqrr / 1000` minutes. `z` bit 0 = south, bit 1 = east.

### 0x9E — Waypoint Definition (15 bytes) — Transmit

Used to define a waypoint on the bus. Complex multi-field format.

## Utility Messages

### 0x30 / 0x80 — Set Lamp Intensity (3 bytes)

**Format**: `30 00 0x` or `80 00 0x`

`x` = intensity: 0=off, 4=low, 8=medium, 0xC=high

### 0x99 — Compass Variation (3 bytes)

**Format**: `99 00 xx`

`xx` = variation in degrees west (signed; negative = east)

### 0x9A — Version String (12 bytes)

Contains product version information broadcast by devices on power-up.

### 0x90 — Device Identification (5 bytes — variable length)

**Format**: `90 z2 xx yy ...`

`z` identifies device type. Used on power-up or in response to 0xA4 query.

### 0xA4 — Broadcast Query (5 or 9 bytes)

Sent by a device to request all other devices on the bus to identify themselves. Devices respond with 0x90.

### 0x38 — Codelock Data (4 bytes)

Used by Raymarine ST60+ instruments with code lock feature.

## NMEA Bridge ID (AK-Homberger specific)

**Format**: `90 00 A3` (3 bytes)

Sent every 10 seconds by the AK-Homberger remote to maintain compatibility with SeaTalk-NG converters. From the code:
```cpp
const uint16_t ST_NMEA_BridgeID[] = { 0x190, 0x00, 0xA3 };
```
The 9th bit is set on byte 0 (0x190 = 0x90 with bit 8 set).

## Implemented in AK-Homberger Project Only

| Command | Length | Description |
|---|---|---|
| 0x90 | 3 | NMEA Bridge ID (0x190 with 9-bit flag) |
| 0xA8 | 6 | Alarm control (beep on/off via 0x1A8 with 9-bit) |

The beep commands use a non-standard format:
```
Beep On:  0xA8 0x53 0x80 0x00 0x00 0xD3
Beep Off: 0xA8 0x43 0x80 0x00 0x00 0xC3
```

## Units and Scaling Reference

| Measurement | Raw Encoding | Real-World Value | Notes |
|---|---|---|---|
| Heading | integer | degrees (0-359) | 3-byte compass encoding |
| Depth | `xxxx` | `xxxx / 10` feet | 0.1 ft resolution |
| Wind angle | `xxyy` | `xxyy / 2` degrees | signed |
| Wind speed | `(xx&0x7f)*10 + y` | knots (or m/s) | 0.1 kt resolution |
| Water speed | `xxxx` | `xxxx / 10` kt | 0.1 kt resolution |
| SOG | `xxxx` | `xxxx / 10` kt | 0.1 kt resolution |
| Trip log | `xxxxx` | `xxxxx / 100` nm | 0.01 nm resolution |
| Total log | `xxxx` | `xxxx / 10` nm | 0.1 nm resolution |
| Temperature | `xxxx` | `(xxxx-100)/10` °C | 0.1 °C resolution |
| Rudder | byte | degrees (signed) | 1° resolution |
| RPM | `yyzz` | RPM | 16-bit signed |
| Latitude | deg + min | `dd mm.mmm` | minutes × 1000 |
| Longitude | deg + min | `ddd mm.mmm` | minutes × 1000 |

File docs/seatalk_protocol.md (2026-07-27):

# SeaTalk 1 Protocol Reference

## 1. Physical Layer

SeaTalk 1 is a single-wire bus running at 12V nominal with open-collector signaling.

| Property | Value |
|---|---|
| Bus voltage | 12V nominal, pulled high via 10K resistor |
| Logic 1 (idle) | Bus line high (12V) |
| Logic 0 (active) | Bus line driven low (GND) |
| Drive type | Open-collector (wired-AND) |
| Cable | 3-wire: +12V, Signal (ST), GND |

The bus is **inverted** relative to typical UART. Idle state is high (12V). Start bit is a high-to-low transition.

### Interface Circuit (BenchPilot discrete transistor design)

The BenchPilot board uses two discrete transistors (BC557 PNP, BC547 NPN) as an inverting level shifter between 12V SeaTalk and 3.3V ESP32 GPIO:

- **Transmit path**: ESP32 TX (GPIO 22) → R4 (3.9K) → Q2 (BC547 NPN) base. Q2 collector tied to SeaTalk DATA, emitter to GND. R3 (10K) pull-down on TX line keeps Q2 off during ESP32 boot.
- **Receive path**: SeaTalk DATA → R2 (2.2K) to 12V, R1 (10K) to Q1 (BC557 PNP) base. Q1 emitter tied to 12V. Q1 collector → R6 (27K) → ESP32 RX (GPIO 35) with R5 (6.8K) pull-down to GND.
- **Pull-up**: 10K resistor from SeaTalk line to +12V (on the Raymarine bus backbone).

Signal flow:

| SeaTalk bus | Receive (Q1) | ESP32 RX | Transmit (Q2) | SeaTalk bus |
|---|---|---|---|---|
| 12V (idle)  | OFF | 0V (LOW)  | ESP32 TX 0V | OFF → 12V |
| 0V (active) | ON | ~2.5V (HIGH) | ESP32 TX 3.3V | ON → 0V |

**Both RX and TX are inverting paths.** The firmware must compensate:

| Path | Inversion | Compensation |
|---|---|---|
| RX | Q1 PNP inverts (12V→LOW, 0V→HIGH) | `uart_set_line_inverse(UART_NUM_2, UART_SIGNAL_RXD_INV)` |
| TX | Q2 NPN inverts (0V→OFF→12V, 3.3V→ON→0V) | `uart_set_line_inverse(UART_NUM_2, UART_SIGNAL_TXD_INV)` |

See `docs/SeaTalkToESP32-Circuit.txt` or `docs/SeaTalkToESP32-Circuit.png` for the full schematic.

### Interface Circuit (Homberger design — reference only, not used here)

The AK-Homberger circuit uses a 74LS07 open-collector hex buffer for level translation between the 12V SeaTalk bus and 5V Arduino GPIO:

- **Transmit path**: Arduino TX → 74LS07 buffer input → open-collector output with 68K series resistor (R2) to SeaTalk line. When low, pulls bus to GND.
- **Receive path**: SeaTalk line via 68K (R2) → 74LS07 buffer input → output with 10K pull-up (R5) to Arduino RX. 5.1V Zener (D1) clamps voltage. 27K pulldown (R3) provides bleed path.
- **Pull-up**: 10K resistor (R1) from SeaTalk line to +12V.

Key difference: The 74LS07 is **non-inverting**, so only RX needs firmware inversion (the UART idle-HIGH maps through correctly for TX). Our discrete transistor circuit inverts both paths.

## 2. Serial Format

| Parameter | Value |
|---|---|
| Baud rate | **4800** baud |
| Data bits | **8** (LSB first) |
| Extra bit | **9th bit** — command/address marker |
| Parity | None |
| Stop bits | 1 |
| Byte format | `start + 8 data + command + stop` |

### Bit Timing

| Period | Duration | Notes |
|---|---|---|
| Bit interval | 208,333 ns (208.3 μs) | 1/4800 s |
| Start bit sample delay | 52,083 ns (52 μs) | 1/4 bit period after falling edge |
| Full byte time | ~2.29 ms | 11 bit periods |
| Inter-byte guard | 10 bit periods (~2.08 ms) | After transmission, bus waits idle |

### 9th Bit (Command Bit)

The 9th bit is the defining feature of SeaTalk:

- **1** (high) = first byte of a new datagram (command/address byte)
- **0** (low) = subsequent bytes within the same datagram (data byte)

The 9th bit is NOT parity. It functions as a datagram frame marker, allowing receivers to resynchronize on the bus.

AK-Homberger stores bytes as `uint16_t` with bit 8 (0x100) set for command bytes:

```
0x186 = binary 1 1000 0110
                ^--- 9th bit = 1 (command byte)
                    ^^^^^^^^--- lower 8 bits = 0x86
```

### Start Bit Detection

A falling edge (high→low transition) on the idle bus signals a start bit. The receiver:
1. Detects falling edge via GPIO interrupt
2. Waits 52 μs (1/4 bit period) before sampling first data bit
3. Samples subsequent bits every 208.3 μs
4. After 8 data bits + 1 command bit, checks stop bit (must be high)

If stop bit is low, the byte is discarded (misalignment recovery strategy).

### Stop Bit Validation

From `seatalk_transport_layer.c:138-145`:
```c
if (!bit_value) {
    // stop bit needs to be high. If not, we are misaligned
    // with the actual bytes and must discard this byte.
    // Eventually "walk" around to correct start/stop alignment.
    set_bus_state(BUS_STATE_IDLE);
    return 0;
}
```

## 3. Bus Arbitration (CSMA/CD)

SeaTalk uses a Carrier Sense Multiple Access with Collision Detection (CSMA/CD) protocol:

### Protocol

1. **Listen before talk**: Before transmitting, drain all incoming bytes from UART buffer (wait for bus silence).
2. **Transmit byte-by-byte**: Send each byte, then immediately read back from the bus.
3. **Collision detection**: If the received byte does not match the transmitted byte, a collision occurred.
4. **Backoff**: Wait a random interval (2-50 ms), then retry up to 5 times.

### AK-Homberger Implementation (`sendDatagram`)

```
for each of 5 retry attempts:
    drain UART RX buffer
    for each byte in datagram:
        write byte to UART
        delay 3ms
        read back from UART
        if received != sent → collision, break
    if all bytes OK → return success
    delay random(2, 50ms)
return failure
```

### James Roscoe Implementation (Linux)

Uses a bus state machine with four states:

```
BUS_STATE_IDLE → BUS_STATE_RECEIVING → BUS_STATE_WAIT_FOR_IDLE
              → BUS_STATE_TRANSMITTING
```

- During transmission, each byte is compared against what appears on the bus
- If mismatch: `cancel_datagram()` — drains remaining bytes, returns to IDLE
- After transmitting, bus idles for 10 bit periods (WAIT_FOR_IDLE) before next transmission
- High-priority commands can interrupt lower-priority sensor transmissions

### Collision Flow

```
Transmitter sends byte
    ↓
Transmitter reads byte back from bus
    ↓
if (read_byte != sent_byte):
    cancel_datagram()     ← collision detected
    wait
    retry from start
```

## 4. Packet / Datagram Structure

### General Format

```
+--------+--------+--------+--------+--------+
| Byte 0 | Byte 1 | Byte 2 | Byte 3 |  ...   | Byte N
| CMD    | LEN    | DATA_0 | DATA_1 |  ...   | DATA_N-2
+--------+--------+--------+--------+--------+
 9th=1     9th=0    9th=0    9th=0           9th=0
```

| Offset | Field | Description |
|---|---|---|
| 0 | Command | Message type identifier. 9th bit = 1 |
| 1 | Length+Flags | `[High nibble: flags/qualifiers][Low nibble: payload length]` |
| 2..N-1 | Payload | Message-specific data bytes. N = (low nibble of byte 1) + 3 |
| N | Checksum | Optional. Present only in specific message types (0x82, 0x85, 0x86) |

### Length Encoding

The low nibble of byte 1 encodes the payload length:

```
total_datagram_bytes = (byte1 & 0x0F) + 3
payload_bytes = total_datagram_bytes - 3  (= low nibble of byte 1)
```

Example: `0x21` → low nibble = 1 → total = 4 bytes, payload = 1 byte
Example: `0x26` → low nibble = 6 → total = 9 bytes, payload = 6 bytes

### Second Byte High Nibble

The high nibble often carries additional flags or qualifiers specific to the message type. For example:

- `build_autopilot_status()`: high nibble of byte 1 encodes compass heading bits
- `build_lamp_intensity()`: high nibble of byte 1 encodes intensity level
- `build_autopilot_command()`: high nibble identifies remote type (1=Z101, 2=ST600R)

### Initialization Pattern

From `seatalk_datagram.c:113-118`:
```c
void initialize_datagram(char *datagram, int datagram_number,
                         int total_length, int high_nibble_of_second_byte) {
    datagram[0] = datagram_number;
    datagram[1] = (total_length - 3) + (high_nibble_of_second_byte << 4);
    for (int i = 2; i < total_length; i++) { datagram[i] = 0; }
}
```

## 5. Checksum Calculation

SeaTalk uses different checksum schemes depending on the message type:

### A. Complement Checksum (0x86, 0x85, 0x82)

For messages with command byte 0x86, 0x85, and 0x82, the checksum is the **bitwise complement** of the associated data byte(s):

```c
int complement_checksum(int value) {
    return value ^ 0xff;  // bitwise NOT
}
```

**Command 0x86** (autopilot keystroke): `86 21 <cmd> <cmd ^ 0xFF>`
- `0x86, 0x21, 0x01, 0xFE` — Auto command (0x01 ^ 0xFF = 0xFE)
- `0x86, 0x21, 0x07, 0xF8` — +1 degree (0x07 ^ 0xFF = 0xF8)

**Command 0x85** (navigation to waypoint): `85 x6 ... <yf> 00 <yf ^ 0xFF>`
- Checksum covers byte 6, stored in byte 8
- Validated as `(yf | yf_comp) == 0xFF`

**Command 0x82** (target waypoint name): Each 6-bit character is stored with its complement in the next byte:
```
xx !xx yy !yy zz !zz
```
Validated as `(xx + xx_comp) == 0xFF`

### B. No Checksum (most messages)

Most SeaTalk messages (0x00, 0x10, 0x11, 0x20, 0x84, 0x89, 0x8C, etc.) do NOT have a checksum byte. The message is validated by:
1. Correct length (from byte 1 low nibble)
2. Correct 9th bit framing
3. Valid stop bit

### C. Checksum Summary

| Command | Checksum type | Validation |
|---|---|---|
| 0x82 | Complement per byte | `(xx + !xx) == 0xFF` |
| 0x85 | Complement of byte 6 in byte 8 | `(yf | yf_comp) == 0xFF` |
| 0x86 | Complement of byte 2 in byte 3 | `(yy | yy_comp) == 0xFF` |
| All others | No checksum byte | Length + framing only |

## 6. Receive Pipeline (James Roscoe Linux Architecture)

```
GPIO pin interrupt (falling edge)
    ↓
initiate_seatalk_receive_character()
    ↓  (start bit timer)
seatalk_receive_bit()  ← called at 208.3 μs intervals
    ↓
seatalk_byte_received(byte, command_bit)
    ↓
handle_seatalk_datagram(datagram)
    ↓
update_seatalk_state(datagram) ← giant switch on byte 0
```

### State machine per received byte

```
command_bit == 1:
    reset receive buffer (start new datagram)
    store byte 0 (command)

command_bit == 0 (first data byte = byte 1):
    store byte 1
    extract length from low nibble
    set remaining byte counter

command_bit == 0 (subsequent bytes):
    store byte
    decrement remaining counter
    if counter == 0: dispatch datagram to handler
```

## 7. Transmit Pipeline

```
Command or sensor data ready
    ↓
wake_transmitter() → initiate_seatalk_transmitter()
    ↓
seatalk_transmit_bit()  ← called at 208.3 μs intervals
    ↓
  bit -1: check can_transmit(), get next byte, set start bit (low)
  bit 0-7: send data bits LSB first
  bit 8: send command bit (1 for first byte, 0 otherwise)
  bit 9: send stop bit (high), signal byte complete
```

After byte completion, the transmitter checks for more pending bytes. Between datagrams, the bus idles for 10 bit periods.

## 8. NMEA0183 Wrapping (James Roscoe Plugin)

For SeaTalk-over-NMEA0183 (SeaTalk Link converters), messages are wrapped in NMEA sentences:

```
$STALK,<hex_bytes_comma_separated>*<XOR_checksum>
$STALK,84,26,A2,88,40,00,FE,02,06*15
$STALK,86,21,01,FE*4E
```

The checksum is XOR of all bytes between `$` (exclusive) and `*` (exclusive).

## 9. Key References

| Source | Focus | Language |
|---|---|---|
| Thomas Knauf (thomasknauf.de/seatalk.htm) | Original protocol reference | German/English |
| James Roscoe (seatalk library, refs/seatalk/) | Complete C library implementation | C (Linux + µC) |
| AK-Homberger (refs/Seatalk-Autopilot-Remote-Control/) | Arduino autopilot remote | C++ (Arduino) |
| James Roscoe (raymarine_autopilot_pi) | OpenCPN autopilot plugin | C++ (wxWidgets) |
| `docs/SeaTalkToESP32-Circuit.txt` | BenchPilot discrete transistor circuit | — |
| `src/main.cpp` | BenchPilot firmware | C++ |

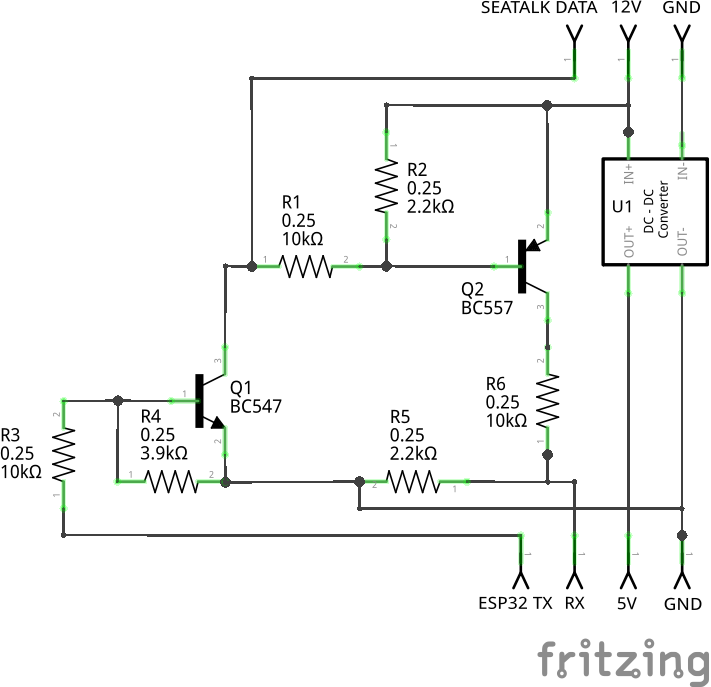
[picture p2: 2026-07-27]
pcb/BenchPilot_260715_schem.png

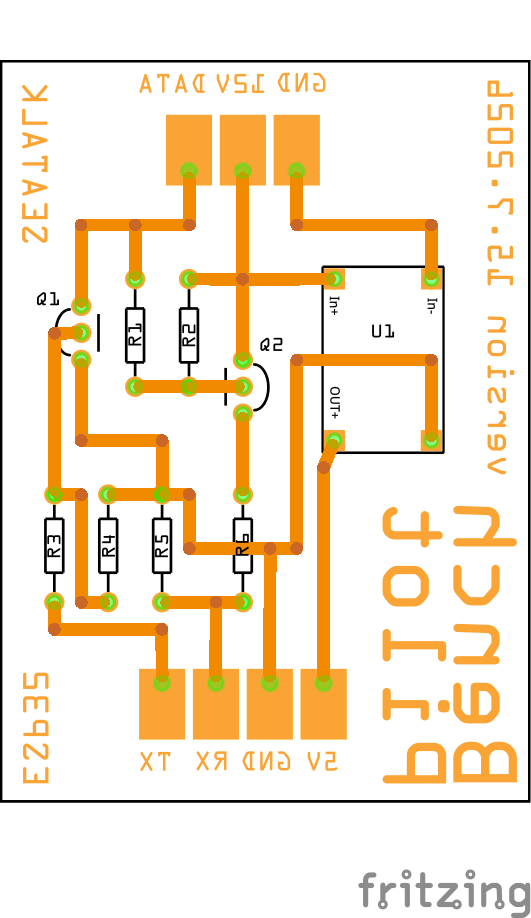
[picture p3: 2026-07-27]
pcb/BenchPilot_260715_pcb.png

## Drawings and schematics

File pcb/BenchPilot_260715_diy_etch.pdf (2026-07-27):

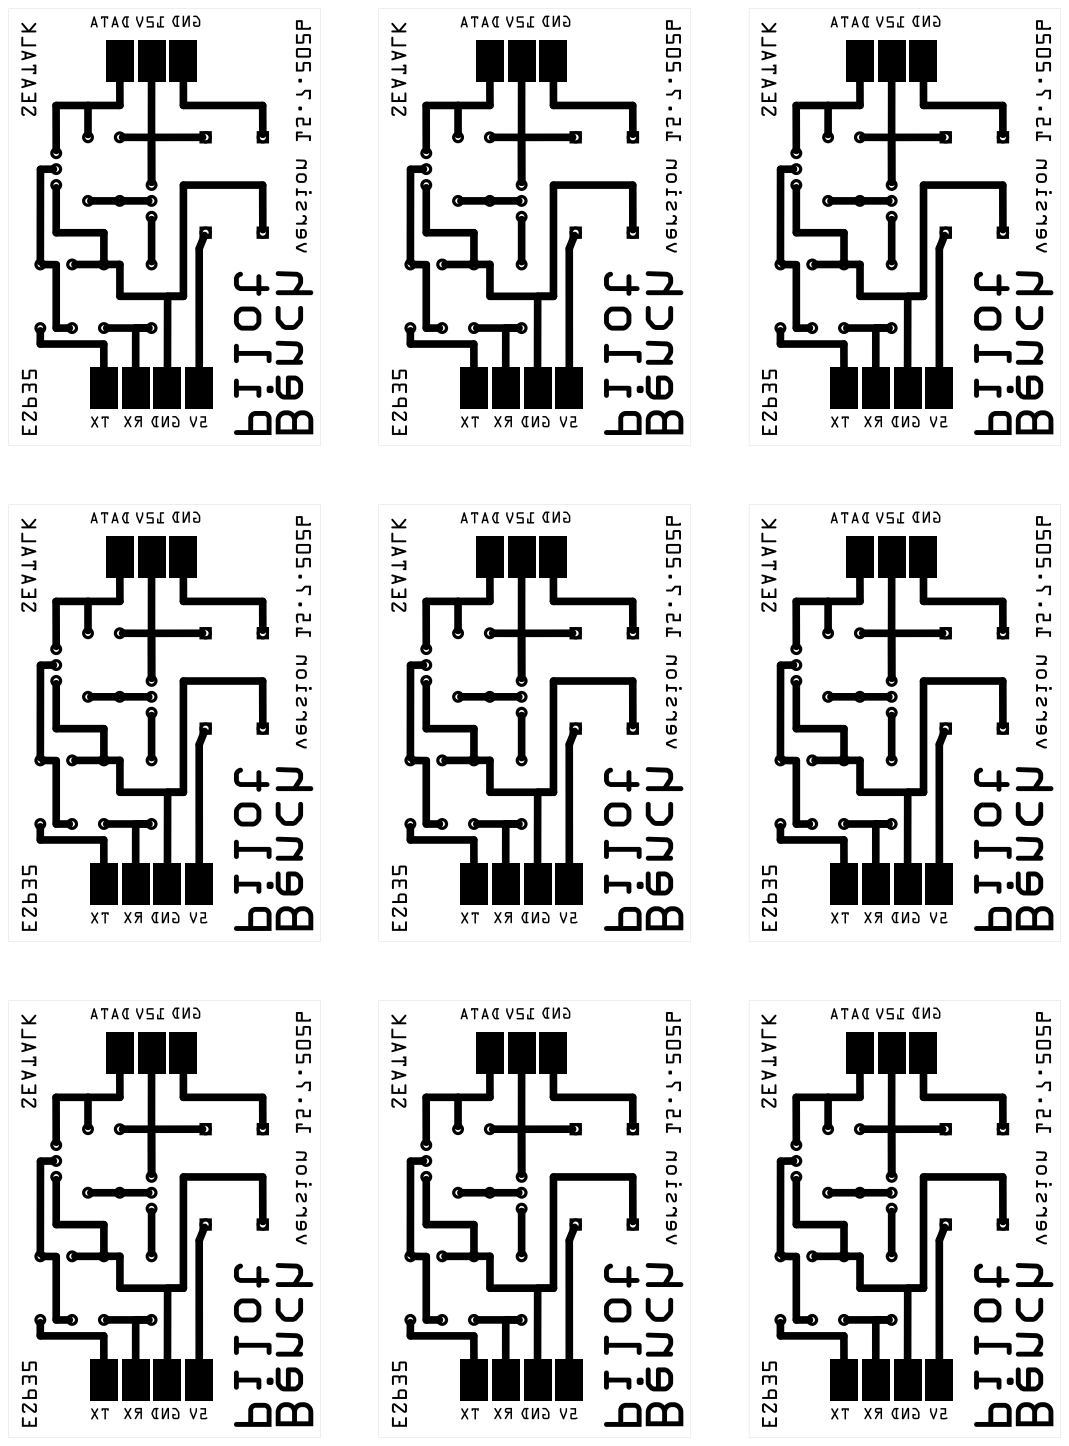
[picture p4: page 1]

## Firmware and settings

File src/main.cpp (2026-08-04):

//======================================================================
//1. INCLUDES & PIN CONFIG
//======================================================================

#include <Arduino.h>
#include <HardwareSerial.h>
#include <driver/uart.h>
#include <soc/uart_reg.h>
#include <TFT_eSPI.h>
#include <WiFi.h>
#include <ArduinoOTA.h>
#include <WebServer.h>
#include <DNSServer.h>
#include <SPI.h>
#include <SD.h>
#include <ESPmDNS.h>

#include "wifi_config.h"

#define SEATALK_BAUD        4800
#define SEATALK_RX_PIN      35
#define TFT_BL_PIN          27
#define MSG_TEXT_LEN        128
#define BUS_IDLE_MS         12
#define AP_RECENT_MS        5000   // alarm recency window (ms since apUpdated)
#define HDG_OVERRIDE_MS     5000   // ms without 0x9C before 0x84 heading is accepted
// Touch layout constants (320×240 CYD)
#define LOG_SCROLL_LEFT     107
#define LOG_SCROLL_RIGHT    214
#define LOG_SCROLL_MID      128
#define LOG_TAP_BOUNDARY    136
#define TOUCH_DEBOUNCE_MS   300

static auto &Seatalk = Serial2;

// TX state
static bool _txActive = false;
static unsigned long _lastBusy = 0;
static uint8_t _suppressEchoCmd = 0;

// Heading TX state (periodic)
static bool _hdgActive = false;
static bool _hdgAutoDrift = true;
static uint16_t _hdgDeg = 0;
static unsigned long _hdgInterval = 250;
static unsigned long _lastHdgTx = 0;
static float _hdgFrac = 0;

#define XPT2046_IRQ 36
#define XPT2046_MOSI 32
#define XPT2046_MISO 39
#define XPT2046_CLK 25
#define XPT2046_CS 33
// --- SD Card Logging ---
#define SD_CS       5
#define SD_SCK      18
#define SD_MOSI     23
#define SD_MISO     19
#define SD_LOG_PCT  90

static File logFile;
static int logNumber = 0;

//======================================================================
//2. DRIVERS — SoftSPI, XPT2046 touch
//======================================================================

// --- SoftSPI: bit-banged SPI driver (inherits SPIClass for SPI transaction API) ---
class SoftSPI : public SPIClass {
    void wait(uint_fast8_t del) { for (uint_fast8_t i = 0; i < del; i++) asm volatile("nop"); }
    uint8_t _cke, _ckp, _delay = 2;
    uint8_t _miso, _mosi, _sck, _order = MSBFIRST;
public:
    SoftSPI(uint8_t mosi, uint8_t miso, uint8_t sck) : _miso(miso), _mosi(mosi), _sck(sck) {}
    void begin() { pinMode(_mosi, OUTPUT); pinMode(_miso, INPUT); pinMode(_sck, OUTPUT); }
    void end()   { pinMode(_mosi, INPUT); pinMode(_miso, INPUT); pinMode(_sck, INPUT); }
    void setBitOrder(uint8_t o) { _order = o & 1; }
    void setDataMode(uint8_t mode) {
        switch (mode) {
            case SPI_MODE0: _ckp = 0; _cke = 0; break;
            case SPI_MODE1: _ckp = 0; _cke = 1; break;
            case SPI_MODE2: _ckp = 1; _cke = 0; break;
            case SPI_MODE3: _ckp = 1; _cke = 1; break;
        }
        digitalWrite(_sck, _ckp ? HIGH : LOW);
    }
    void setClockDivider(uint32_t div) {
        switch (div) {
            case SPI_CLOCK_DIV2:   _delay = 2;   break;
            case SPI_CLOCK_DIV4:   _delay = 4;   break;
            case SPI_CLOCK_DIV8:   _delay = 8;   break;
            case SPI_CLOCK_DIV16:  _delay = 16;  break;
            case SPI_CLOCK_DIV32:  _delay = 32;  break;
            case SPI_CLOCK_DIV64:  _delay = 64;  break;
            case SPI_CLOCK_DIV128: _delay = 128; break;
            default:               _delay = 128; break;
        }
    }
    uint8_t transfer(uint8_t val) {
        uint8_t out = 0;
        if (_order == MSBFIRST) {
            uint8_t v2 =
                ((val & 0x01) << 7) | ((val & 0x02) << 5) |
                ((val & 0x04) << 3) | ((val & 0x08) << 1) |
                ((val & 0x10) >> 1) | ((val & 0x20) >> 3) |
                ((val & 0x40) >> 5) | ((val & 0x80) >> 7);
            val = v2;
        }
        uint8_t del = _delay >> 1, bval = 0;
        int sck = (_ckp) ? HIGH : LOW;
        for (uint8_t bit = 0; bit < 8; bit++) {
            if (_cke) { sck ^= 1; digitalWrite(_sck, sck); wait(del); }
            digitalWrite(_mosi, (val & (1 << bit)) ? HIGH : LOW);
            wait(del);
            sck ^= 1; digitalWrite(_sck, sck);
            bval = digitalRead(_miso);
            if (_order == MSBFIRST) { out <<= 1; out |= bval; }
            else { out >>= 1; out |= bval << 7; }
            wait(del);
            if (!_cke) { sck ^= 1; digitalWrite(_sck, sck); }
        }
        return out;
    }
    uint16_t transfer16(uint16_t data) {
        union { uint16_t val; struct { uint8_t lsb; uint8_t msb; }; } in, out;
        in.val = data;
        if (_order == MSBFIRST) { out.msb = transfer(in.msb); out.lsb = transfer(in.lsb); }
        else { out.lsb = transfer(in.lsb); out.msb = transfer(in.msb); }
        return out.val;
    }
};

// --- Touchscreen reimplementation (no external library dependency) ---
class TS_Point {
public:
    int16_t x, y, z;
    TS_Point() : x(0), y(0), z(0) {}
    TS_Point(int16_t x, int16_t y, int16_t z) : x(x), y(y), z(z) {}
    bool operator==(TS_Point p) { return p.x == x && p.y == y && p.z == z; }
    bool operator!=(TS_Point p) { return p.x != x || p.y != y || p.z != z; }
};

#define Z_THRESHOLD     400
#define Z_THRESHOLD_INT 75
#define MSEC_THRESHOLD  3
#define SPI_SETTING     SPISettings(2000000, MSBFIRST, SPI_MODE0)

class XPT2046_TouchscreenSOFTSPI {
    uint8_t csPin, tirqPin, rotation = 1;
    int16_t xraw = 0, yraw = 0, zraw = 0;
    uint32_t msraw = 0x80000000;

    static int16_t besttwoavg(int16_t x, int16_t y, int16_t z) {
        int16_t da = (x > y) ? x - y : y - x;
        int16_t db = (x > z) ? x - z : z - x;
        int16_t dc = (z > y) ? z - y : y - z;
        if (da <= db && da <= dc) return (x + y) >> 1;
        if (db <= da && db <= dc) return (x + z) >> 1;
        return (y + z) >> 1;
    }

    void update(SoftSPI *spi) {
        int16_t data[6];
        if (!isrWake) return;
        uint32_t now = millis();
        if (now - msraw < MSEC_THRESHOLD) return;

        spi->beginTransaction(SPI_SETTING);
        digitalWrite(csPin, LOW);
        spi->transfer(0xB1);
        int16_t z1 = spi->transfer16(0xC1) >> 3;
        int z = z1 + 4095;
        int16_t z2 = spi->transfer16(0x91) >> 3;
        z -= z2;

        if (z >= Z_THRESHOLD) {
            spi->transfer16(0x91);
            data[0] = spi->transfer16(0xD1) >> 3;
            data[1] = spi->transfer16(0x91) >> 3;
            data[2] = spi->transfer16(0xD1) >> 3;
            data[3] = spi->transfer16(0x91) >> 3;
        } else {
            data[0] = data[1] = data[2] = data[3] = 0;
        }
        data[4] = spi->transfer16(0xD0) >> 3;
        data[5] = spi->transfer16(0) >> 3;
        digitalWrite(csPin, HIGH);
        spi->endTransaction();

        if (z < 0) z = 0;
        if (z < Z_THRESHOLD) { zraw = 0; if (z < Z_THRESHOLD_INT && 255 != tirqPin) isrWake = false; return; }
        zraw = z;

        int16_t x = besttwoavg(data[0], data[2], data[4]);
        int16_t y = besttwoavg(data[1], data[3], data[5]);

        if (z >= Z_THRESHOLD) {
            msraw = now;
            switch (rotation) {
                case 0: xraw = 4095 - y; yraw = x; break;
                case 1: xraw = x; yraw = y; break;
                case 2: xraw = y; yraw = 4095 - x; break;
                default: xraw = 4095 - x; yraw = 4095 - y; break;
            }
        }
    }

public:
    volatile bool isrWake = true;
    constexpr XPT2046_TouchscreenSOFTSPI(uint8_t cspin, uint8_t tirq = 255) : csPin(cspin), tirqPin(tirq) {}

    bool begin(SoftSPI *spi) {
        spi->begin();
        pinMode(csPin, OUTPUT);
        digitalWrite(csPin, HIGH);
        if (255 != tirqPin) {
            pinMode(tirqPin, INPUT_PULLUP);
            attachInterrupt(digitalPinToInterrupt(tirqPin), [] { if (isrPinptr) isrPinptr->isrWake = true; }, FALLING);
            isrPinptr = this;
        }
        return true;
    }

    TS_Point getPoint(SoftSPI *spi) { update(spi); return TS_Point(xraw, yraw, zraw); }
    bool tirqTouched() { return isrWake; }
    bool touched(SoftSPI *spi) { update(spi); return zraw >= Z_THRESHOLD; }
    void readData(SoftSPI *spi, uint16_t *x, uint16_t *y, uint8_t *z) { update(spi); *x = xraw; *y = yraw; *z = zraw; }
    bool bufferEmpty() { return (millis() - msraw) < MSEC_THRESHOLD; }
    uint8_t bufferSize() { return 1; }
    void setRotation(uint8_t n) { rotation = n % 4; }

private:
    static XPT2046_TouchscreenSOFTSPI *isrPinptr;
};
XPT2046_TouchscreenSOFTSPI *XPT2046_TouchscreenSOFTSPI::isrPinptr = nullptr;

static SoftSPI tsi(XPT2046_MOSI, XPT2046_MISO, XPT2046_CLK);
static XPT2046_TouchscreenSOFTSPI touchscreen(XPT2046_CS, XPT2046_IRQ);
static int touchX, touchY;
static unsigned long lastBtnPress = 0;

enum SensorIdx : uint8_t { SI_DEPTH, SI_WIND_ANGLE, SI_WIND_SPEED, SI_STW, SI_SOG, SI_COG, SI_WATER_TEMP, SI_END };

//======================================================================
//3. DATA MODEL — BoatData, widgets, bands, colors, buttons
//======================================================================

TFT_eSPI tft;
WebServer server(80);
DNSServer dnsServer;

static unsigned long totalBytes = 0;
static bool wifiConnected = false;
static unsigned long lastPacketTime = 0;

struct BoatData {
    // Autopilot (from 0x84)
    int heading = -1;
    int rudder = 0;
    bool rudderValid = false;
    int mode = -1;
    int targetHeading = -1;
    int turnDirection = 0;
    int failureCode = -1;
    bool offCourse = false, windShift = false, largeXTE = false;
    bool noData = false, autoRelease = false;
    unsigned long apUpdated = 0;
    unsigned long last9cMs = 0;

    // Sensors
    int depth = -1, windAngle = -1, windSpeed = -1;
    int stw = -1, sog = -1, cog = -1, waterTemp = -1;
    unsigned long sensorSeen[SI_END] = {0};
    static constexpr int SENSOR_TIMEOUT = 10000;

    // GPS
    int gpsLatDeg = -1, gpsLatMin = -1, gpsLonDeg = -1, gpsLonMin = -1;
    bool gpsLatNorth = true, gpsLonEast = true;
    int gpsSats = -1, gpsHDOP = -1;
    unsigned long gpsSeen = 0;

    int tftRefresh = 0;

    void pushMsg(const char *text);
};
static BoatData g;

// Log slot generation counter — bumped on every pushMsg so the CYD tick and web
// update can detect new traffic without touching the ring.
static uint32_t gSlotsSeq = 0;
static void slotPush(const char *text);

void BoatData::pushMsg(const char *text) {
    slotPush(text);
    gSlotsSeq++;
}

static void buildLogLine(char *buf, size_t sz, unsigned long ts,
                         const uint8_t *data, int len, const char *desc) {
    unsigned long secs = ts / 1000;
    int pos = snprintf(buf, sz, "%02lu:%02lu:%02lu,",
                       secs / 3600, (secs / 60) % 60, secs % 60);
    for (int i = 0; i < len && pos < (int)sz - 10; i++)
        pos += snprintf(buf + pos, sz - pos, " %02X", data[i]);
    pos += snprintf(buf + pos, sz - pos, ", %s", desc);
}

// 192x192 PNG, 1324 bytes — dark bg + cyan circle
// --- Display model — single source of truth for widget order ---
enum Widget : uint8_t { W_MODE, W_HEADING, W_RUDDER, W_ALARMS, W_TARGET, W_BTNS, W_END };
static const Widget widgetOrder[] = { W_MODE, W_HEADING, W_TARGET, W_ALARMS, W_RUDDER, W_BTNS, W_END };

// --- CYD layout bands — explicit y/height so widgets can never overlap ---
// Screen 320x240: top zone y=0..136 (buttons start y=136), status bar y=228..240.
struct Band { int16_t y, h; };
static const Band BAND[W_END] = {
    {  2, 18 },  // W_MODE    font2 16px → glyphs 3..19
    { 22, 54 },  // W_HEADING font7 48px → glyphs 25..73
    {110, 22 },  // W_RUDDER  track x4..315 y110..131, white-bordered box w/ value pill
    { 98, 10 },  // W_ALARMS  font1 8px  → glyphs 99..106
    { 78, 18 },  // W_TARGET  font2 16px → glyphs 79..95
    {  0,  0 },  // W_BTNS    fixed button coords, no band
};
static const Band STATUS_BAND = { 228, 12 };  // bottom status bar, font1

// --- Render-state cache — dirty-checking for flicker-free redraws ---
struct BandState { char text[56]; int16_t w; uint16_t color; bool valid; };
static BandState gBand[W_END];
static BandState gStatusBand;
static bool gBtnsDrawn = false;
static bool gOtaActive = false;
struct RdrState { int8_t val; bool valid; bool drawn; int8_t numW; };
static RdrState gRdr = { 0, false, false, 0 };
static bool gLogView = false;
static int gLogScroll = 0;
static int gLogLastSeq = -1;
static int gLogFrozenNewest = -1;
static int gLogViewDir = 0;
static int _flashIdx = -1;
static unsigned long _flashEnd = 0;
static int _driftFlashIdx = -1;

// Persistent log display slot cache
#define MAX_SLOTS 50
static struct Slot { char key[64]; int count; char text[MSG_TEXT_LEN]; } gSlots[MAX_SLOTS];
static int gSlotCount = 0;
static int gNewestSlot = -1;

// Force full redraw of all bands after any fillScreen (WiFi change, OTA).
static void invalidateBands() {
    for (int i = 0; i < W_END; i++) gBand[i].valid = false;
    gStatusBand.valid = false;
    gRdr.drawn = false;
    gBtnsDrawn = false;
}

// ============= TFT color constants =============
// Conversion to 24-bit web colors (for HTML/JS) — run:
//   python3 -c "c=0xVVVV;r=(c>>11&31)*255//31;g=(c>>5&63)*255//63;b=(c&31)*255//31;print(f'#{r:02x}{g:02x}{b:02x}')"
#define TFT_MODE_STBY   0xF81F  // magenta, matches fallback
#define TFT_MODE_ACT    0x07E0  // green
#define TFT_MODE_FALL   TFT_MODE_STBY
#define TFT_HDG         0x07FF  // cyan
#define TFT_HDG_SIM     0xFFA0  // yellow — simulated heading
#define TFT_RDR_NORM    0x07FF  // cyan
#define TFT_RDR_EXT     0xF800  // red
#define TFT_ALARM       0xF800  // red
#define TFT_ALARM_WARN  0xFB20  // orange
#define TFT_TRG         0x07E0  // green — starboard turn
#define TFT_TRG_PORT    0xC800  // red — port turn
#define TFT_TRG_ON      0x07FF  // cyan — at course (matches heading)
#define TFT_BTN_AP      0x4002  // dark red
#define TFT_BTN_AP_HI   0xD000  // bright red (active AP mode)
#define TFT_BTN_ADJ     TFT_BTN_NAV
#define TFT_BTN_NAV     0x008C  // dark blue
#define TFT_BTN_FLUXSIM    0xD640  // yellow (active)
#define TFT_BTN_FLUXSIM_DIM 0x4A69  // dark grey (inactive)

// --- Log view muted colors (grey tones → desaturated hues) ---
#define TFT_LOG_TS   0x6C54  // muted steel blue
#define TFT_LOG_HX   0x6C4D  // muted sage green
#define TFT_LOG_SEP  0x7B4F  // muted mauve
#define TFT_LOG_DESC 0xD508  // muted amber
#define TFT_LOG_HI   0xFDC0  // bright amber (newest entry)
#define TFT_HL_BG   0x4980  // warm amber bg for newest row
#define TFT_LOG_SEP_HI 0xE5B8  // bright mauve (counter on hl)
#define TFT_LOG_TS_HI  0x7EFC  // bright steel blue (ts on hl)
#define TFT_LOG_HX_HI  0x87C0  // bright sage green (hex on hl)
#define TFT_LOG_DESC_TX 0xD400  // muted orange (TX)
#define TFT_LOG_HI_TX   0xFD40  // bright orange (TX newest)

// --- Touchscreen buttons ---
// Convention: when adding a button here, also add a <button> in handleRoot() HTML
// with the same api= value and onclick handler. Layout must match between both.
#define NUM_BUTTONS 14
struct ButtonDef {
    const char *api;
    const char *label;
    uint8_t cmd;
    uint32_t color;
    int x, y, w, h;
};
static ButtonDef btns[NUM_BUTTONS] = {
    {"auto",     "AUTO",  0x01, TFT_BTN_AP,  220, 136, 96,  56},
    {"standby",  "STBY",  0x02, TFT_BTN_AP,  4,   136, 96,  56},
    {"plus1",    "+1",    0x07, TFT_BTN_ADJ, 164, 136, 52,  27},
    {"minus1",   "-1",    0x05, TFT_BTN_ADJ, 108, 136, 52,  27},
    {"plus10",   "+10",   0x08, TFT_BTN_ADJ, 164, 167, 52,  27},
    {"minus10",  "-10",   0x06, TFT_BTN_ADJ, 108, 167, 52,  27},
    {"wind",     "WIND",  0x23, TFT_BTN_NAV, 4,   198, 96,  24},
    {"fluxsim",  "SIM",   0xff, TFT_BTN_FLUXSIM,108, 198, 52,  24},
    {"fixedhdg", "SET",   0xF9, TFT_BTN_FLUXSIM,164, 198, 52,  24},
    {"track",    "TRACK", 0x28, TFT_BTN_NAV, 220, 198, 96,  24},
    {"hdg_m10",  "-10",   0xFE, TFT_BTN_FLUXSIM, 4,  198, 48, 24},
    {"hdg_m1",   "-1",    0xFD, TFT_BTN_FLUXSIM, 52, 198, 48, 24},
    {"hdg_p1",   "+1",    0xFC, TFT_BTN_FLUXSIM, 220, 198, 48, 24},
    {"hdg_p10",  "+10",   0xFB, TFT_BTN_FLUXSIM, 268, 198, 48, 24},
};

static int seatalkHeading(uint8_t byte1, uint8_t byte2) {
    uint8_t u = (byte1 >> 4) & 0x0F;
    int deg = ((u & 3) * 90)
            + ((byte2 & 0x3F) * 2)
            + ((u & 0x0C) ? (((u & 0x0C) == 0x0C) ? 2 : 1) : 0);
    if (deg > 360) deg -= 360;
    return deg;
}

// Mode display helpers — single source of truth for TFT + JSON
static const char *modeLabel(int mode) {
    return mode == 2 ? "AUTO" : mode == 4 ? "VANE"
         : mode == 8 ? "TRACK" : mode == 0 ? "STANDBY" : "MODE";
}
static uint16_t modeColor(int mode) {
    return mode == 2 || mode == 4 || mode == 8 ? TFT_MODE_ACT
         : mode == 0 ? TFT_MODE_STBY : TFT_MODE_FALL;
}
static const char *modeColorName(int mode) {
    return mode == 2 || mode == 4 || mode == 8 ? "green"
         : mode == 0 ? "yellow" : "dim";
}

//======================================================================
//4. SD LOGGING
//======================================================================

// --- SD card helpers ---
static int findNextLogNumber() {
    int maxN = 0;
    File root = SD.open("/");
    if (root) {
        File entry = root.openNextFile();
        while (entry) {
            if (!entry.isDirectory()) {
                String n(entry.name());
                if (n.startsWith("LOG_") && n.endsWith(".TXT")) {
                    int v = n.substring(4, 8).toInt();
                    if (v > maxN) maxN = v;
                }
            }
            entry.close();
            entry = root.openNextFile();
        }
        root.close();
    }
    return maxN + 1;
}
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
void loop() {
    ArduinoOTA.handle();
    server.handleClient();
    dnsServer.processNextRequest();

    if (WiFi.status() == WL_CONNECTED) {
        if (!wifiConnected) {
            wifiConnected = true;
            drawStatusBar();
        }
    } else if (wifiConnected) {
        wifiConnected = false;
        drawStatusBar();
        WiFi.reconnect();
    }

    sendHeading();

    if (!gLogView && _driftFlashIdx >= 0) {
        flashButton(_driftFlashIdx);
        _driftFlashIdx = -1;
    }

    if (!_txActive) {
        while (Seatalk.available() > 0) {
            uint8_t b = Seatalk.read();
            totalBytes++;
            lastPacketTime = millis();
            _lastBusy = lastPacketTime;
            processByte(b);
        }
    }

    updateSpeaker();

    if (touchscreen.tirqTouched() && touchscreen.touched(&tsi)) {
        TS_Point p = touchscreen.getPoint(&tsi);
        touchX = map(p.x, 200, 3700, 1, 320);
        touchY = map(p.y, 240, 3800, 1, 240);
        unsigned long now = millis();
        if (now - lastBtnPress >= TOUCH_DEBOUNCE_MS) {
            if (gLogView) {
                if (touchX < LOG_SCROLL_LEFT || touchX >= LOG_SCROLL_RIGHT) {
                    logViewScroll((touchY < LOG_SCROLL_MID) ? 1 : -1);
                } else {
                    gLogView = false;
                    invalidateBands();
                    tft.fillScreen(TFT_BLACK);
                }
                lastBtnPress = now;
            } else {
                bool handled = false;
                for (int i = 0; i < NUM_BUTTONS; i++) {
                    auto &b = btns[i];
                    if (touchX >= b.x && touchX < b.x + b.w &&
                        touchY >= b.y && touchY < b.y + b.h) {
                        if (_hdgActive && (b.cmd == 0x23 || b.cmd == 0x28)) continue;
                        flashButton(i);
                        lastBtnPress = now;
                        if (b.cmd == 0xff) {
                            if (_hdgActive && _hdgAutoDrift) stopHdg_int();
                            else simHdg_auto(g.heading >= 0 ? g.heading : 180);
                        } else if (b.cmd == 0xF9) {
                            if (_hdgActive && !_hdgAutoDrift) stopHdg_int();
                            else simHdg_fixed(g.heading >= 0 ? g.heading : 180);
                        } else if (b.cmd == 0xFE) {
                            _hdgDeg = (_hdgDeg + 350) % 360; _hdgFrac = 0; gBtnsDrawn = false;
                        } else if (b.cmd == 0xFD) {
                            _hdgDeg = (_hdgDeg + 359) % 360; _hdgFrac = 0; gBtnsDrawn = false;
                        } else if (b.cmd == 0xFC) {
                            _hdgDeg = (_hdgDeg + 1) % 360; _hdgFrac = 0; gBtnsDrawn = false;
                        } else if (b.cmd == 0xFB) {
                            _hdgDeg = (_hdgDeg + 10) % 360; _hdgFrac = 0; gBtnsDrawn = false;
                        } else {
                            pressAutopilotButton(b);
                        }
                        handled = true;
                        break;
                    }
                }
                if (!handled && touchY < LOG_TAP_BOUNDARY) {
                    gLogView = true;
                    gLogScroll = 0;
                    gLogLastSeq = -1;
                    tft.fillScreen(TFT_BLACK);
                    lastBtnPress = now;
                }
            }
        }
    }

    if (_flashIdx >= 0 && millis() > _flashEnd) {
        drawAllButtons();
        _flashIdx = -1;
    }
    updateDisplay();
}

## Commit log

2026-07-27 Initial commit: BenchPilot v1
    ESP32 based SeaTalk 1 autopilot interface and monitor for
    Raymarine SmartPilot S3 course computers. Converts an ESP32 CYD
    (ESP32-2432S028R) into a wireless control head, replacing the
    physical ST6002 on the bench or on the boat.
    [BenchPilot_260715.fzz]
2026-07-27 fix log view ghosting by clearing each line fully before redraw; update README with DIY etch and PVC housing details
    [BenchPilot_260715.fzz]
2026-07-27 fix foam board thickness and simplify housing description
2026-07-27 suppress lv_conf.h warning by switching to LV_CONF_SKIP
2026-07-28 README: correct printer type (must be laser for toner transfer)
2026-07-30 fluxsim: grey inactive button, +/-10/+/-1 heading adj buttons replacing wind/track
    log display: full dedup via persistent slot cache, 4-column fixed-width layout,
    newest row highlight with brighter text on amber background, font 2 (bigger)
    on TFT, hex wrap to 2nd line on overflow, tap scroll 1/3 page per tap
    steering sim: rudder-driven heading drift in AUTO mode, proportional blink
    feedback on +/-1 buttons, last known heading used for fluxsim activation
    log format: all messages uppercase via buildLogLine, no more -- placeholders,
    heading simulation gets proper timestamps, dedup key matches TFT and webapp
    webapp: inline log file browser with delete all, dynamic footer nav per view,
    live/li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
    [main.cpp]
2026-07-30 fix: centered live|logs nav bar with grid layout, single back arrow, logs highlight gold, 200-msg JSON window matching TFT counter
    [main.cpp]
2026-07-30 fix: grid footer width 100%, uniform .85em font in logs, render skips when paused
    [main.cpp]
2026-07-30 fix: persistent footer grid via cell IDs, setFooter updates cells not innerHTML, width 100% in CSS
    [main.cpp]
2026-07-31 fix: dedup keys, uppercase labels, 3-char placeholders, quieter web tick
    - msgKey: use last comma to exclude hex bytes from dedup key; skip '-' sign
    so all same-type messages collapse to one slot on both TFT and web view
    - TFT log view: wider hex column (126px), indent wrapped hex continuations
    - Web view: vertical-align:top on log spans, percentage col widths (5/8/52%)
    - Uppercase all parser descriptions: HDG, TRG, RDR, DPT, TEMP, SYS, DATAGRAM, etc.
    - Replace ---/-- placeholders with 3-letter field abbreviations (HDG/RDR/TRG/MOD/LOG)
    - Web message tick: add GainNode at 0.07 to match button beep volume level
    [main.cpp]
2026-07-31 fix: heading placeholder uses font 2 instead of font 7 on TFT
    Font 7 is a 7-segment font without alphabetic glyphs, so 'HDG'
    rendered as blank. Switch to font 2 (16px) for the placeholder
    while keeping font 7 for numeric heading values.
    [main.cpp]
2026-07-31 feat: CYD log timestamps MM:SS, x1 wrap at 999, TX/RX log markers with colored desc, tri-color target heading arrows, SIM/SET dual FLUXSIM modes, drift regardless of AUTO, SD log parity
    - CYD live log: show MM:SS instead of HH:MM:SS, shift columns for more description space
    - Fix hex-wrap overflow into status bar area (last line black mask)
    - x1 counter wraps at 999, flips to 1 (CYD + web)
    - Target heading: tri-color arrow (green starboard, red port, cyan at-course ±3°)
    - TX log messages prefixed with '> ' marker, rendered in muted orange; RX stays plain amber
    - FLUXSIM split into SIM (auto-drift) and SET (manual) buttons on CYD and web
    - SIM drift works regardless of autopilot mode (remov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
    [main.cpp]
2026-07-31 fix: BandState tracks color to prevent stale display on color-only changes; log real 0x89 datagram bytes instead of fake 0x9C; add debug fields to /status JSON
    [main.cpp]
2026-08-01 fix: clipboard log copy with aligned columns; CYD description text wrapping for long messages; zero-padded 3-digit counter without x prefix
    [main.cpp]
2026-08-01 fix: word-boundary description wrapping, continuation in desc column; clipboard copy uses tabs
    [main.cpp]
2026-08-01 fix: hex continuation alignment by splitting at space boundary; prevent empty line when both hex and desc wrap
    [main.cpp]
2026-08-01 fix: desc continuation keeps leading space for alignment with hex continuation
    [main.cpp]
2026-08-01 fix: switch log view to monospace font 4 for pixel-perfect column alignment
    [main.cpp]
2026-08-01 revert: switch log view back to font 2 (font 4 was not monospace)
    [main.cpp]
2026-08-01 fix: desc continuation strips leading space so text aligns at X_DESC on both lines
    [main.cpp]
2026-08-01 fix: desc continuation keeps one leading space from split boundary
    [main.cpp]
2026-08-01 fix: desc continuation indented with 2 extra leading spaces
    [main.cpp]
2026-08-01 fix: reduce desc continuation indent to 1 extra space
    [main.cpp]
2026-08-04 feat: unify log view and webview on shared slot table
    Replace the 300-entry RAM ring buffer with a single authoritative gSlots
    table used by both the CYD display and the webview. Counts are now
    cumulative since boot (999->1 wrap), bounded to 50 slots, freeing ~38.4 KB
    static RAM and making /status heap usage bounded (~3-4 KB).
    - BoatData::pushMsg now calls slotPush() + bumps gSlotsSeq generation
    - drawLogView() renders slots directly; tick/redraw via gSlotsSeq
    - /status emits "slots" array with count/newest flags, JSON-escaped
    - web JS renders authoritative slots, drops client-side Map/dedup
    Also add plan.txt and abilities.txt project docs.
    [main.cpp]
